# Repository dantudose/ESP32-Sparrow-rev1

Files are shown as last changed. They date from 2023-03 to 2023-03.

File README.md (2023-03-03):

# ESP32-Sparrow-rev1

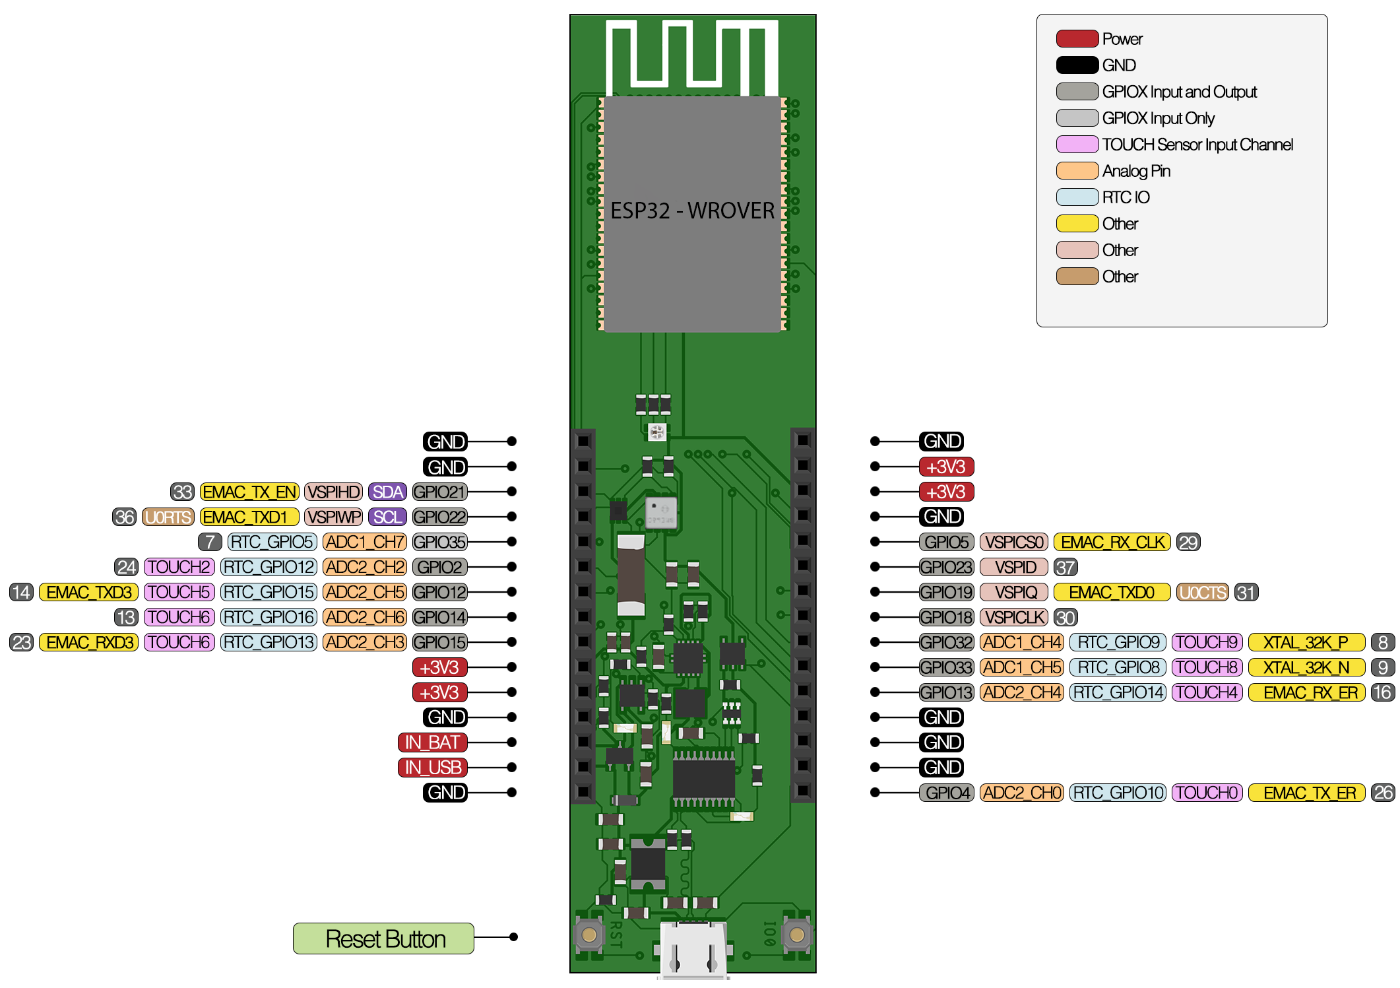
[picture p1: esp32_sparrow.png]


The ESP32 Sparrow is a development board supporting the ESP32-WROVER module. It is fully Arduino-compatible and it comes with two on-board environmental sensors (Bosch temperature, humidity, pressure and air quality BME680 and Lite-On luxmeter LTR308), an RGB LED, expansion headers, a Li-Po charger circuit and a 18650 battery holder and a USB programming interface.

Repository Contents
-------------------

* **/Hardware** - Eagle design files (.brd, .sch)

Documentation
--------------
* **[Hookup Guide](https://ocw.cs.pub.ro/courses/iothings/laboratoare/2022/lab1)** - Basic hookup tutorial for ESP32 Sparrow

License Information
-------------------

This product is _**open source**_! 

Please review the LICENSE file for license information. 

Distributed as-is; no warranty is given.

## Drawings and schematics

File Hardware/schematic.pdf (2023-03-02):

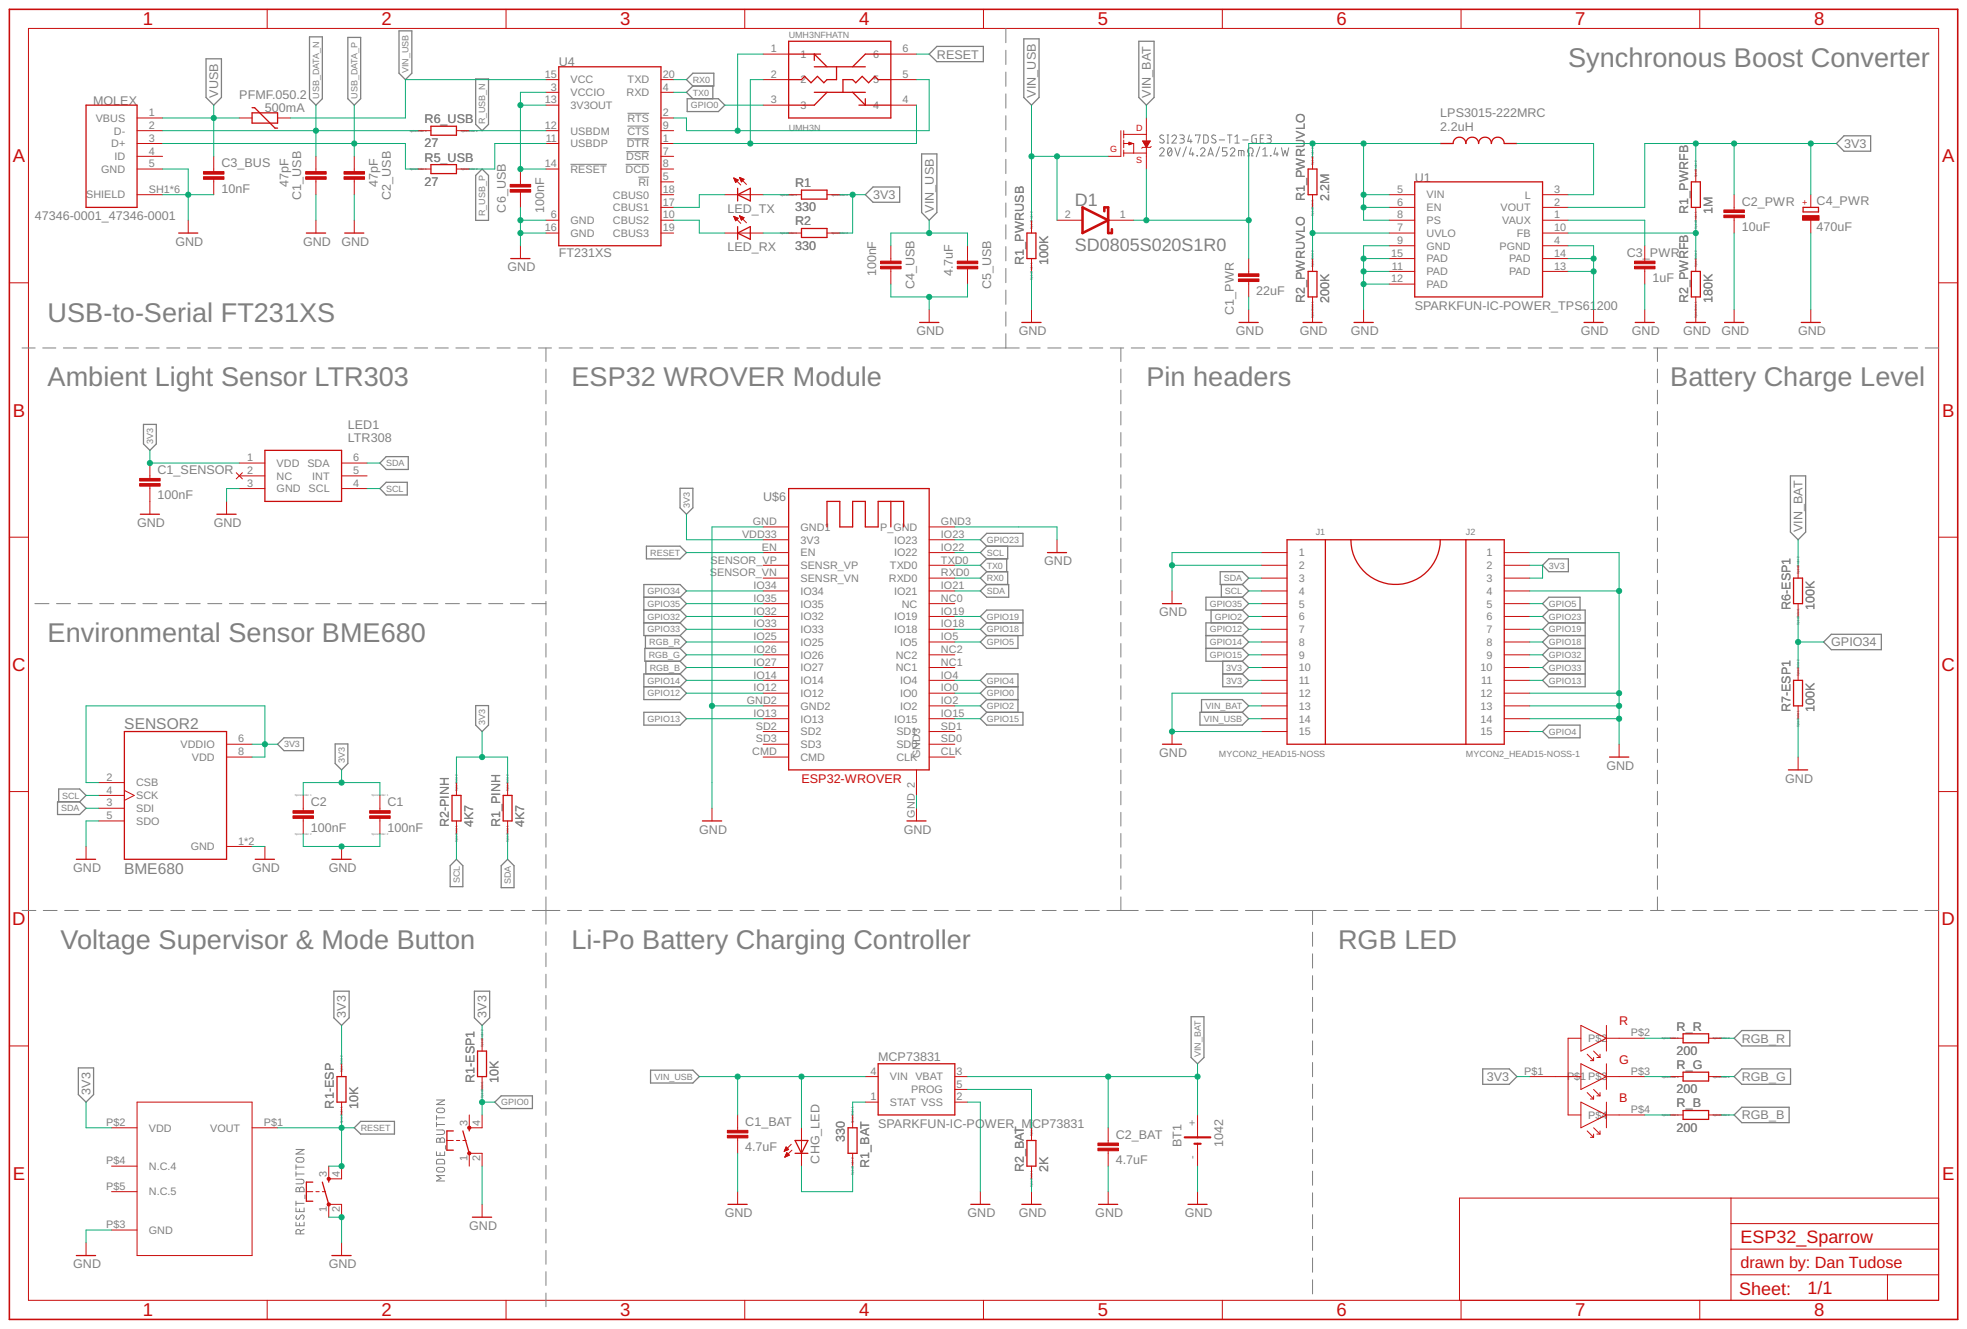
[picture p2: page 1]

UMH3NFHATN

SpiceOrder 1 SpiceOrder 2 SpiceOrder 1 SpiceOrder 2

SpiceOrder 1 SpiceOrder 2

RGB_G | IO27

Voltage Supervisor & Mode Button

Li-Po Battery Charging Controller

SPARKFUN-IC-POWER_MCP73831

drawn by: Dan Tudose
Sheet:

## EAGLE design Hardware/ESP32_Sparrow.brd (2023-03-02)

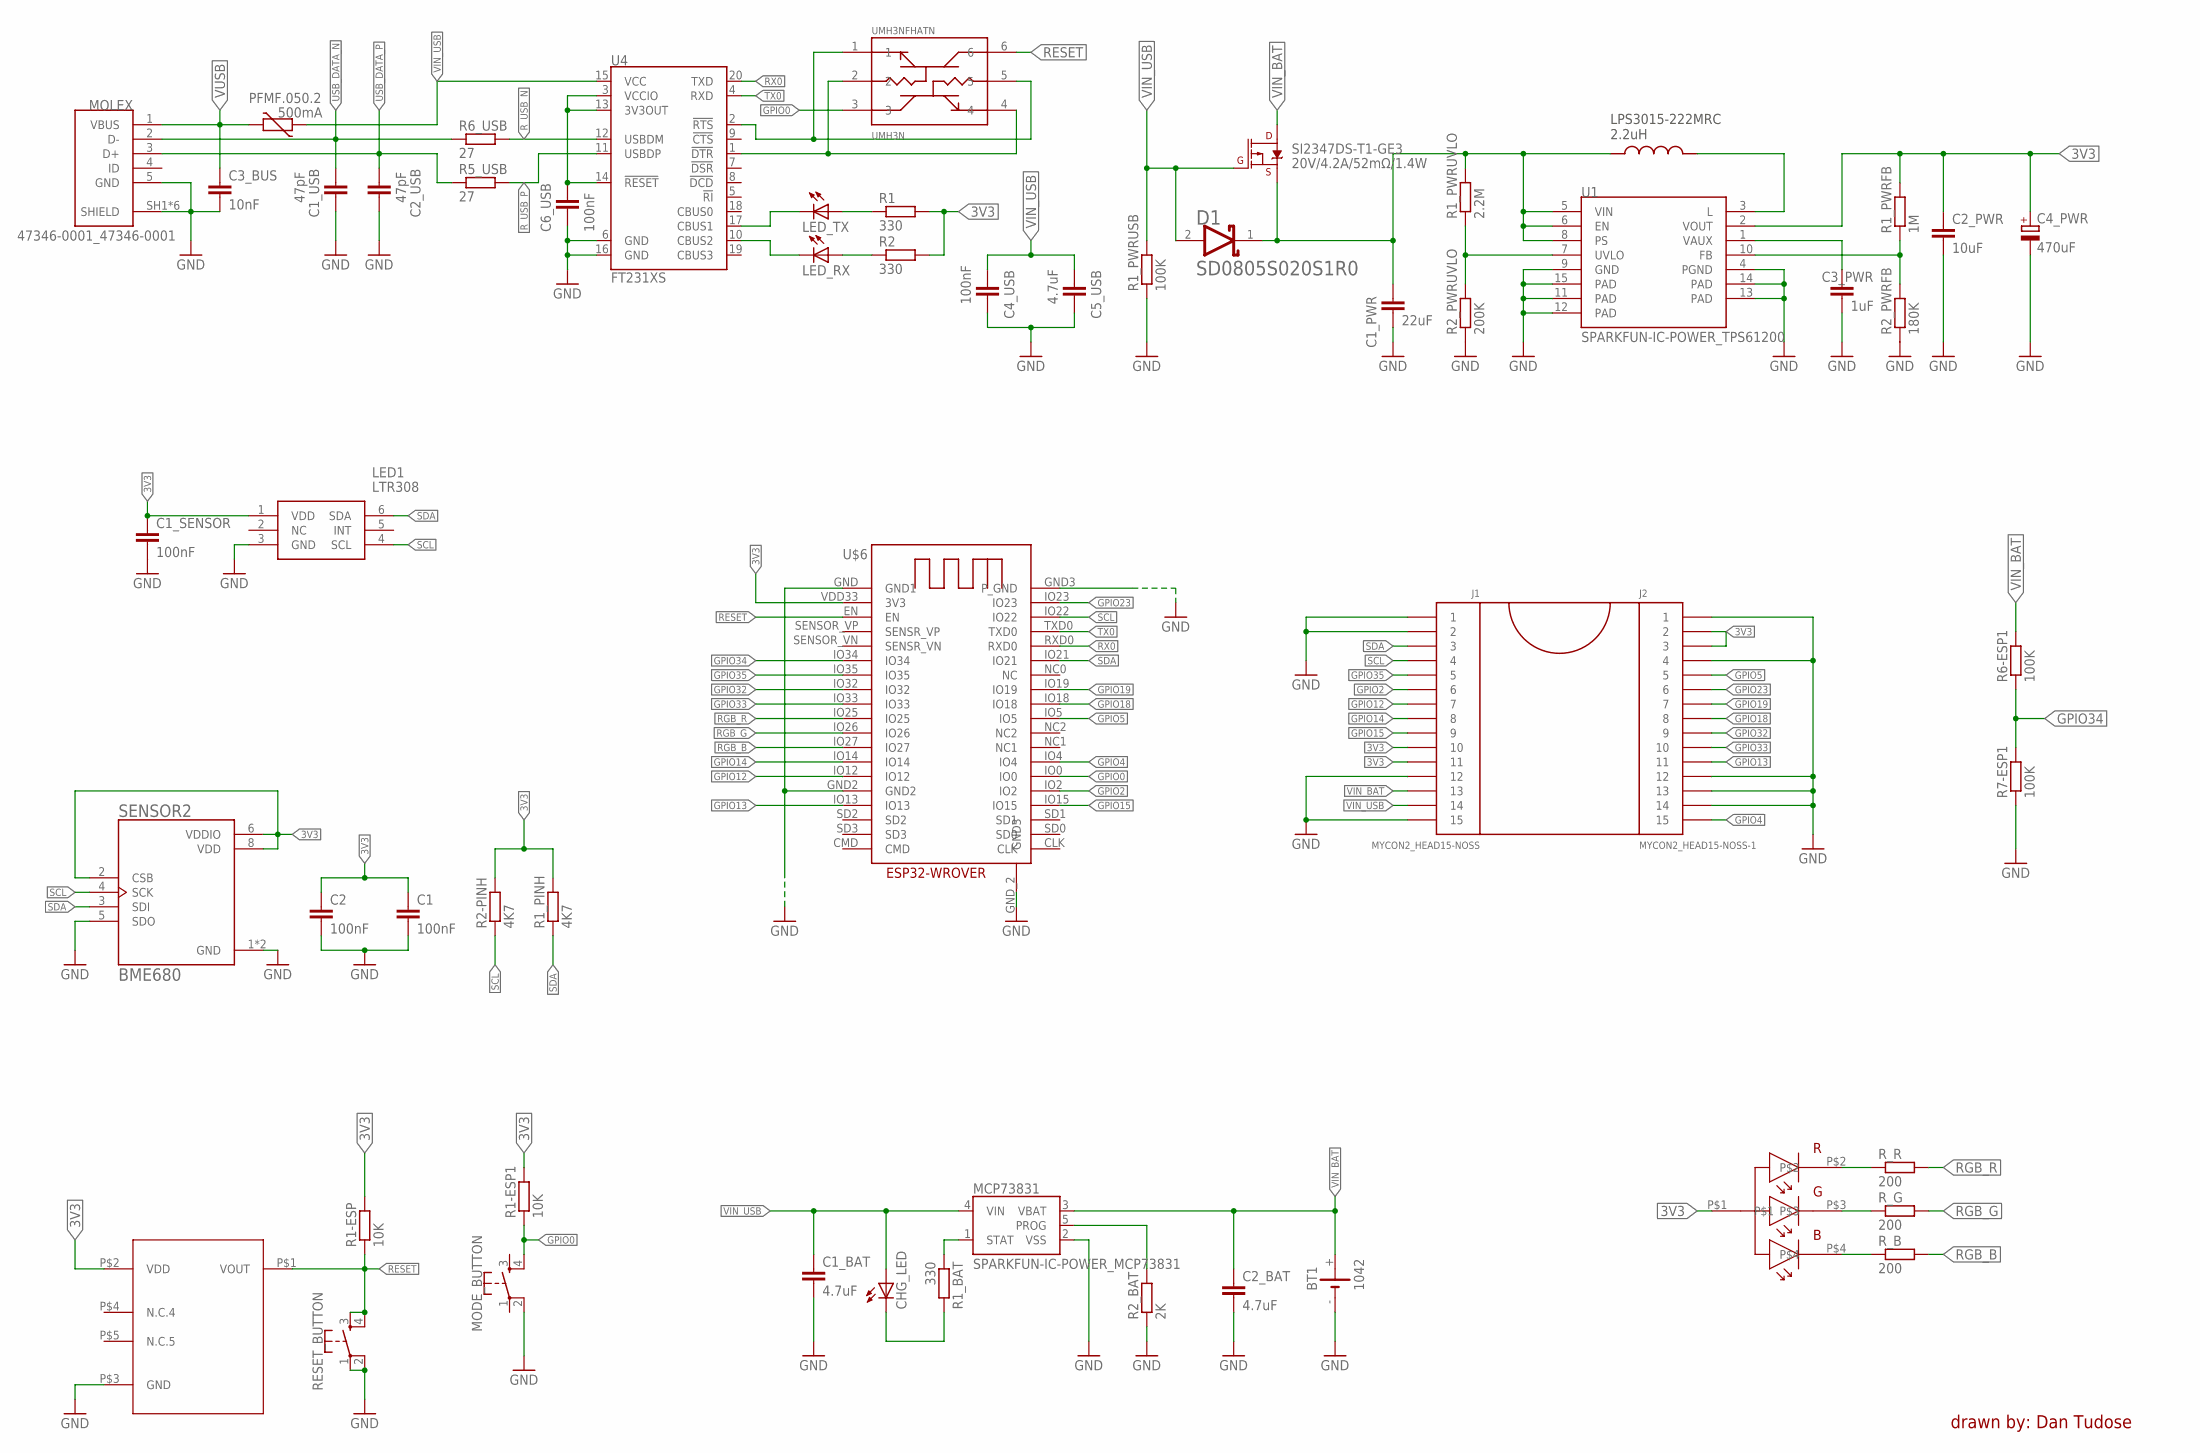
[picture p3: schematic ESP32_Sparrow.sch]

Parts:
BD48E27G-TR: BD48E27G-TR_BD48E27G-TR; BD48E27G-TR_SSOP5
BT1: 1042; BAT_1042
C1, C2: 100nF; EAGLE-LTSPICE_C0402
C1_BAT, C2_BAT, C5_USB: 4.7uF; RCL_C0603
C1_PWR: 22uF; RCL_C0603
C1_SENSOR, C4_USB, C6_USB: 100nF; RCL_C0603
C1_USB, C2_USB: 47pF; RCL_C0603
C2_PWR: 10uF; RCL_C0603
C3_BUS: 10nF; RCL_C0603
C3_PWR: 1uF; RCL_C0603
C4_PWR: 470uF; RCL_D/7343-31R
CHG_LED: ADAFRUIT_LEDCHIP-LED0603; ADAFRUIT_CHIP-LED0603
D1: AVX---SD0805S020S1R0_AVX_SD0805S020S1R0AVX_SD0805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; AVX---SD0805S020S1R0_AVX_SD0805S020S1R0_0
J1: MYCON2_HEAD15-NOSS
J2: MYCON2_HEAD15-NOSS-1
LED1: LTR308; SAMACSYS_PARTS_LTR303ALS01
LED_RX: ADAFRUIT_LEDCHIP-LED0603; ADAFRUIT_CHIP-LED0603
LED_TX: ADAFRUIT_LEDCHIP-LED0603; ADAFRUIT_CHIP-LED0603
MCP73831: SPARKFUN-IC-POWER_MCP73831; SPARKFUN-IC-POWER_SOT23-5
MODE_BUTTON: SPARKFUN-SWITCHES_MOMENTARY-SWITCH-SPST-2-SMD-4.6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; SPARKFUN-SWITCHES_TACTILE_SWITCH_SMD_4.6X2.8MM
MOLEX: 47346-0001_47346-0001; 47346-0001_MOLEX_47346-0001
PFMF.050.2: 500mA; VARISTOR_CT/CN1812
R1, R1_BAT, R2: 330; EAGLE-LTSPICE_R0402
R1-ESP, R1-ESP1: 10K; EAGLE-LTSPICE_R0402
R1_PINH, R2-PINH: 4K7; EAGLE-LTSPICE_R0402
R1_PWRFB: 1M; EAGLE-LTSPICE_R0402
R1_PWRUSB, R6-ESP1, R7-ESP1: 100K; EAGLE-LTSPICE_R0402
R1_PWRUVLO: 2.2M; EAGLE-LTSPICE_R0402
R2_BAT: 2K; EAGLE-LTSPICE_R0402
R2_PWRFB: 180K; EAGLE-LTSPICE_R0402
R2_PWRUVLO: 200K; EAGLE-LTSPICE_R0402
R5_USB, R6_USB: 27; EAGLE-LTSPICE_R0402
RESET_BUTTON: SPARKFUN-SWITCHES_MOMENTARY-SWITCH-SPST-2-SMD-4.6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; SPARKFUN-SWITCHES_TACTILE_SWITCH_SMD_4.6X2.8MM
R_B: 200; EAGLE-LTSPICE_R0402
R_G: 200; EAGLE-LTSPICE_R0402
R_R: 200; EAGLE-LTSPICE_R0402
SENSOR2: BME680; BME680_PSON80P300X300X100-8N
SI2347DS-T1-GE3: 20V/4.2A/52mΩ/1.4W; SPARKFUN-DISCRETESEMI_SOT23-3
U1: SPARKFUN-IC-POWER_TPS61200; SPARKFUN-IC-POWER_QFN-10_PAD
U4: FT231XS; SPARKFUN-IC-COMMS_SSOP20_L
U$2: 150202M153130_150202M153130-RGB; 150202M153130_150202M153130
U$5: LPS3015_LPS3015; LPS3015_LPS3015-222MRC
U$6: ESP32-WROVER_ESP32-WROVER
UMH3NFHATN: UMH3N_UMH3N; UMH3N_SOP65P210X100-6N

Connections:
3V3: BD48E27G-TR.P$2 (VDD), C1.1, C1_SENSOR.1, C2.1, C2_PWR.1, C4_PWR.+, J1.10, J1.11, J2.2, J2.3, LED1.1 (VDD), R1.2, R1-ESP.2, R1-ESP1.2, R1_PINH.2, R1_PWRFB.2, R2.2, R2-PINH.2, SENSOR2.2 (CSB), SENSOR2.6 (VDDIO), SENSOR2.8 (VDD), U1.2 (VOUT), U$2.P$1, U$6.VDD33 (3V3)
GND: BD48E27G-TR.P$3 (GND), BT1.-, C1.2, C1_BAT.2, C1_PWR.2, C1_SENSOR.2, C1_USB.2, C2.2, C2_BAT.2, C2_PWR.2, C2_USB.2, C3_BUS.2, C3_PWR.2, C4_PWR.-, C4_USB.2, C5_USB.2, C6_USB.2, J1.1, J1.2, J1.12, J1.15, J2.1, J2.4, J2.12, J2.13, J2.14, LED1.3 (GND), MCP73831.2 (VSS), MODE_BUTTON.2, MOLEX.5 (GND), MOLEX.SH1 (SHIELD), MOLEX.SH2 (SHIELD), MOLEX.SH3 (SHIELD), MOLEX.SH4 (SHIELD), MOLEX.SH5 (SHIELD), MOLEX.SH6 (SHIELD), R1_PWRUSB.1, R2_BAT.1, R2_PWRFB.1, R2_PWRUVLO.1, R7-ESP1.1, RESET_BUTTON.1, RESET_BUTTON.2, SENSOR2.1 (GND), SENSOR2.5 (SDO), SENSOR2.7 (GND), U1.4 (PGND), U1.9 (GND), U1.11 (PAD), U1.12 (PAD), U1.13 (PAD), U1.14 (PAD), U1.15 (PAD), U4.6 (GND), U4.16 (GND), U$6.GND (GND1), U$6.GND2, U$6.GND3 (P_GND), U$6.GND_2 (GND3)
GPIO0: MODE_BUTTON.4, R1-ESP1.1, U$6.IO0, UMH3NFHATN.3
GPIO2: J1.6, U$6.IO2
GPIO4: J2.15, U$6.IO4
GPIO5: J2.5, U$6.IO5
GPIO12: J1.7, U$6.IO12
GPIO13: J2.11, U$6.IO13
GPIO14: J1.8, U$6.IO14
GPIO15: J1.9, U$6.IO15
GPIO18: J2.8, U$6.IO18
GPIO19: J2.7, U$6.IO19
GPIO23: J2.6, U$6.IO23
GPIO32: J2.9, U$6.IO32
GPIO33: J2.10, U$6.IO33
GPIO34: R6-ESP1.1, R7-ESP1.2, U$6.IO34
GPIO35: J1.5, U$6.IO35
unnamed: R1_PWRUVLO.1, R2_PWRUVLO.2, U1.7 (UVLO)
unnamed: MCP73831.1 (STAT), R1_BAT.1
unnamed: CHG_LED.C, R1_BAT.2
unnamed: MCP73831.5 (PROG), R2_BAT.2
unnamed: R_R.1, U$2.P$2
unnamed: U1.3 (L), U$5.P$2
unnamed: R_G.1, U$2.P$3
unnamed: R_B.1, U$2.P$4
unnamed: R1_PWRFB.1, R2_PWRFB.2, U1.10 (FB)
unnamed: C3_PWR.1, U1.1 (VAUX)
unnamed: C6_USB.1, U4.3 (VCCIO), U4.13 (3V3OUT), U4.14 (!RESET)
unnamed: LED_TX.A, R1.1
unnamed: LED_RX.A, R2.1
unnamed: U4.1 (!DTR), UMH3NFHATN.2, UMH3NFHATN.4
unnamed: LED_TX.C, U4.17 (CBUS1)
unnamed: LED_RX.C, U4.10 (CBUS2)
unnamed: U4.2 (!RTS), UMH3NFHATN.1, UMH3NFHATN.5
RESET: BD48E27G-TR.P$1 (VOUT), R1-ESP.1, RESET_BUTTON.3, RESET_BUTTON.4, U$6.EN, UMH3NFHATN.6
RGB_B: R_B.2, U$6.IO27
RGB_G: R_G.2, U$6.IO26
RGB_R: R_R.2, U$6.IO25
RX0: U4.20 (TXD), U$6.RXD0
R_USB_N: R6_USB.2, U4.12 (USBDM)
R_USB_P: R5_USB.2, U4.11 (USBDP)
SCL: J1.4, LED1.4 (SCL), R2-PINH.1, SENSOR2.4 (SCK), U$6.IO22
SDA: J1.3, LED1.6 (SDA), R1_PINH.1, SENSOR2.3 (SDI), U$6.IO21
TX0: U4.4 (RXD), U$6.TXD0
USB_DATA_N: C1_USB.1, MOLEX.2 (D-), R6_USB.1
USB_DATA_P: C2_USB.1, MOLEX.3 (D+), R5_USB.1
VIN: C1_PWR.1, D1.1 (CATHODE), R1_PWRUVLO.2, SI2347DS-T1-GE3.2 (S), U1.5 (VIN), U1.6 (EN), U1.8 (PS), U$5.P$1
VIN_BAT: BT1.+, C2_BAT.1, J1.13, MCP73831.3 (VBAT), R6-ESP1.2, SI2347DS-T1-GE3.3 (D)
VIN_USB: C1_BAT.1, C4_USB.1, C5_USB.1, CHG_LED.A, D1.2 (ANODE), J1.14, MCP73831.4 (VIN), PFMF.050.2.1, R1_PWRUSB.2, SI2347DS-T1-GE3.1 (G), U4.15 (VCC)
VUSB: C3_BUS.1, MOLEX.1 (VBUS), PFMF.050.2.2

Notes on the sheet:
drawn by: Dan Tudose

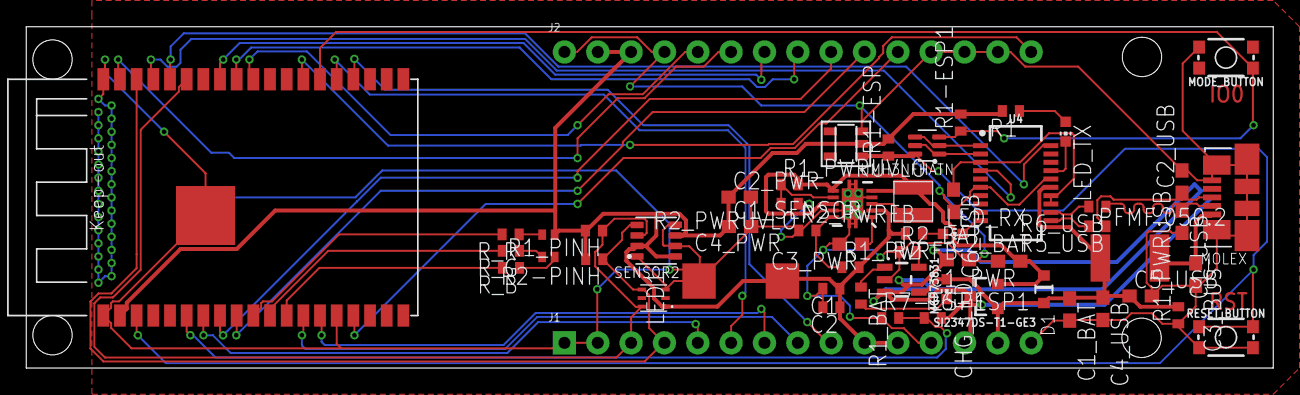
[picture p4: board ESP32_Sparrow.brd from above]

Board: 2 copper layers, 95.0 x 26.0 mm, 57 parts (1 on the bottom side), 50 nets.
